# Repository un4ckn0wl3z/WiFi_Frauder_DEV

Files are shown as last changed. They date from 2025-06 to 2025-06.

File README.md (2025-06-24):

# WiFi Frauder 🚨📡

**WiFi Frauder** is an open-source hardware and firmware project designed to broadcast humorous or custom WiFi SSIDs using an ESP32-based custom PCB.

---

## 🟩 PCB Overview

rev3_pcb_assembly
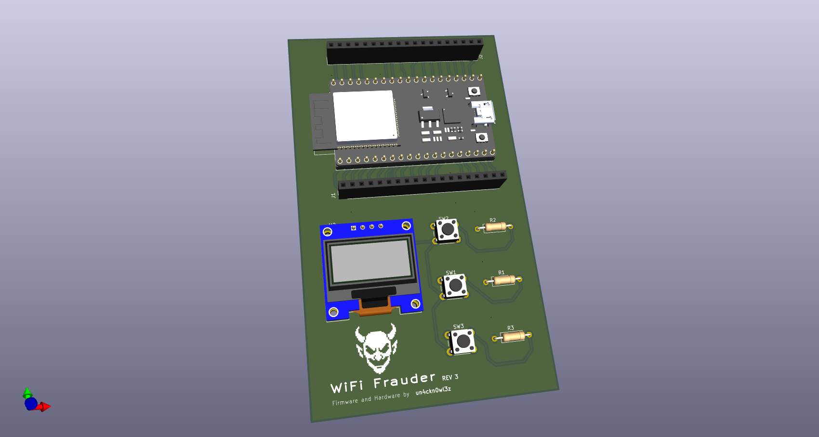
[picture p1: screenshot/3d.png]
3d

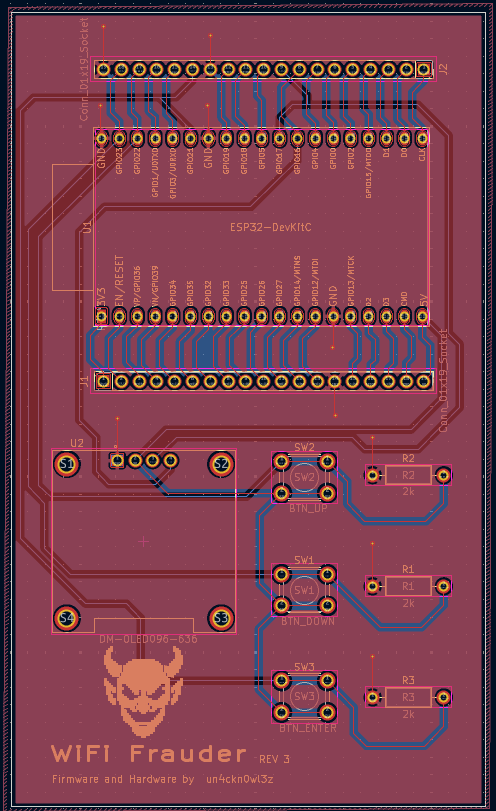
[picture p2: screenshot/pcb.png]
pcb

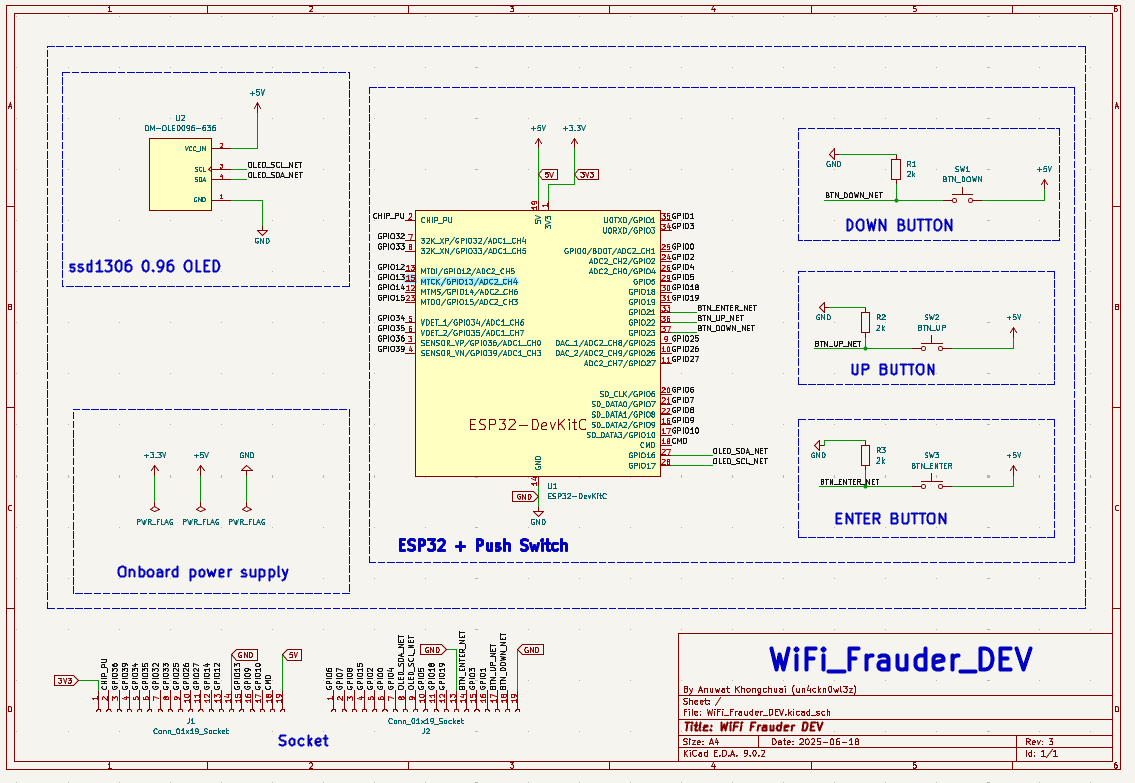
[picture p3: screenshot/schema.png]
schema


---

## 🔧 Features

- Random (Slow) – Randomly spams WiFi SSIDs at a slow rate
- Random (Fast) – Randomly spams WiFi SSIDs at a faster rate
- Custom SSID – Spams WiFi SSIDs based on entries from the SPIFFS config file

---

## To stop spamming
- Press both the UP and DOWN buttons simultaneously to stop spamming.

---

## 🛠️ Hardware

- **Microcontroller**: ESP32 DevKitC 32E (38 pins)
- **Power**: USB or battery-powered
- **Display**: SSD1306 0.96 I2C OLED

PCB design files and schematics are included in the `/pcb` folder.

---

## 📦 Firmware

Written in C++ using the Arduino and FreeRTOS frameworks, built with the PlatformIO toolset.
First, build the SPIFFS file system and edit the SSIDs as you like in the `funny_ssid_list.txt` file located in the `/data` folder.
Then, build the main firmware and upload it to the `WiFi Frauder` device.

---
## Disclaimer

⚠️ Intended for educational and ethical hacking use only. Use responsibly and **never** violate local laws or network policies.

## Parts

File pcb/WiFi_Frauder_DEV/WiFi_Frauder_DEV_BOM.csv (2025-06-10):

Id | Designator | Footprint | Quantity | Designation | Supplier and ref
1 | R2,R1,R3 | C_0805_2012Metric | 3 | 2k
2 | U2 | MODULE_DM-OLED096-636 | 1 | DM-OLED096-636
3 | SW2 | SW_PUSH_6mm | 1 | BTN_UP
4 | SW3 | SW_PUSH_6mm | 1 | BTN_ENTER
5 | U1 | ESP32-DevKitC | 1 | ESP32-DevKitC
6 | SW1 | SW_PUSH_6mm | 1 | BTN_DOWN

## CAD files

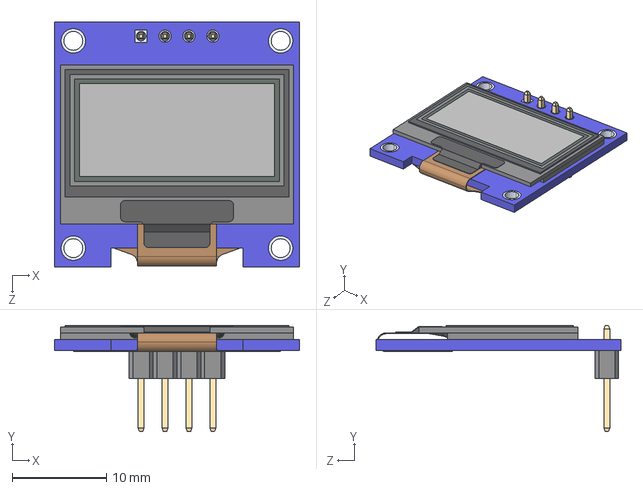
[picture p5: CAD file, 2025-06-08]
pcb/WiFi_Frauder_DEV/DM-OLED096-636/DM-OLED096-636.step
26.0 x 11.3 x 26.0 mm
DM-OLED096-636_Module
DM-OLED096-636_Panel

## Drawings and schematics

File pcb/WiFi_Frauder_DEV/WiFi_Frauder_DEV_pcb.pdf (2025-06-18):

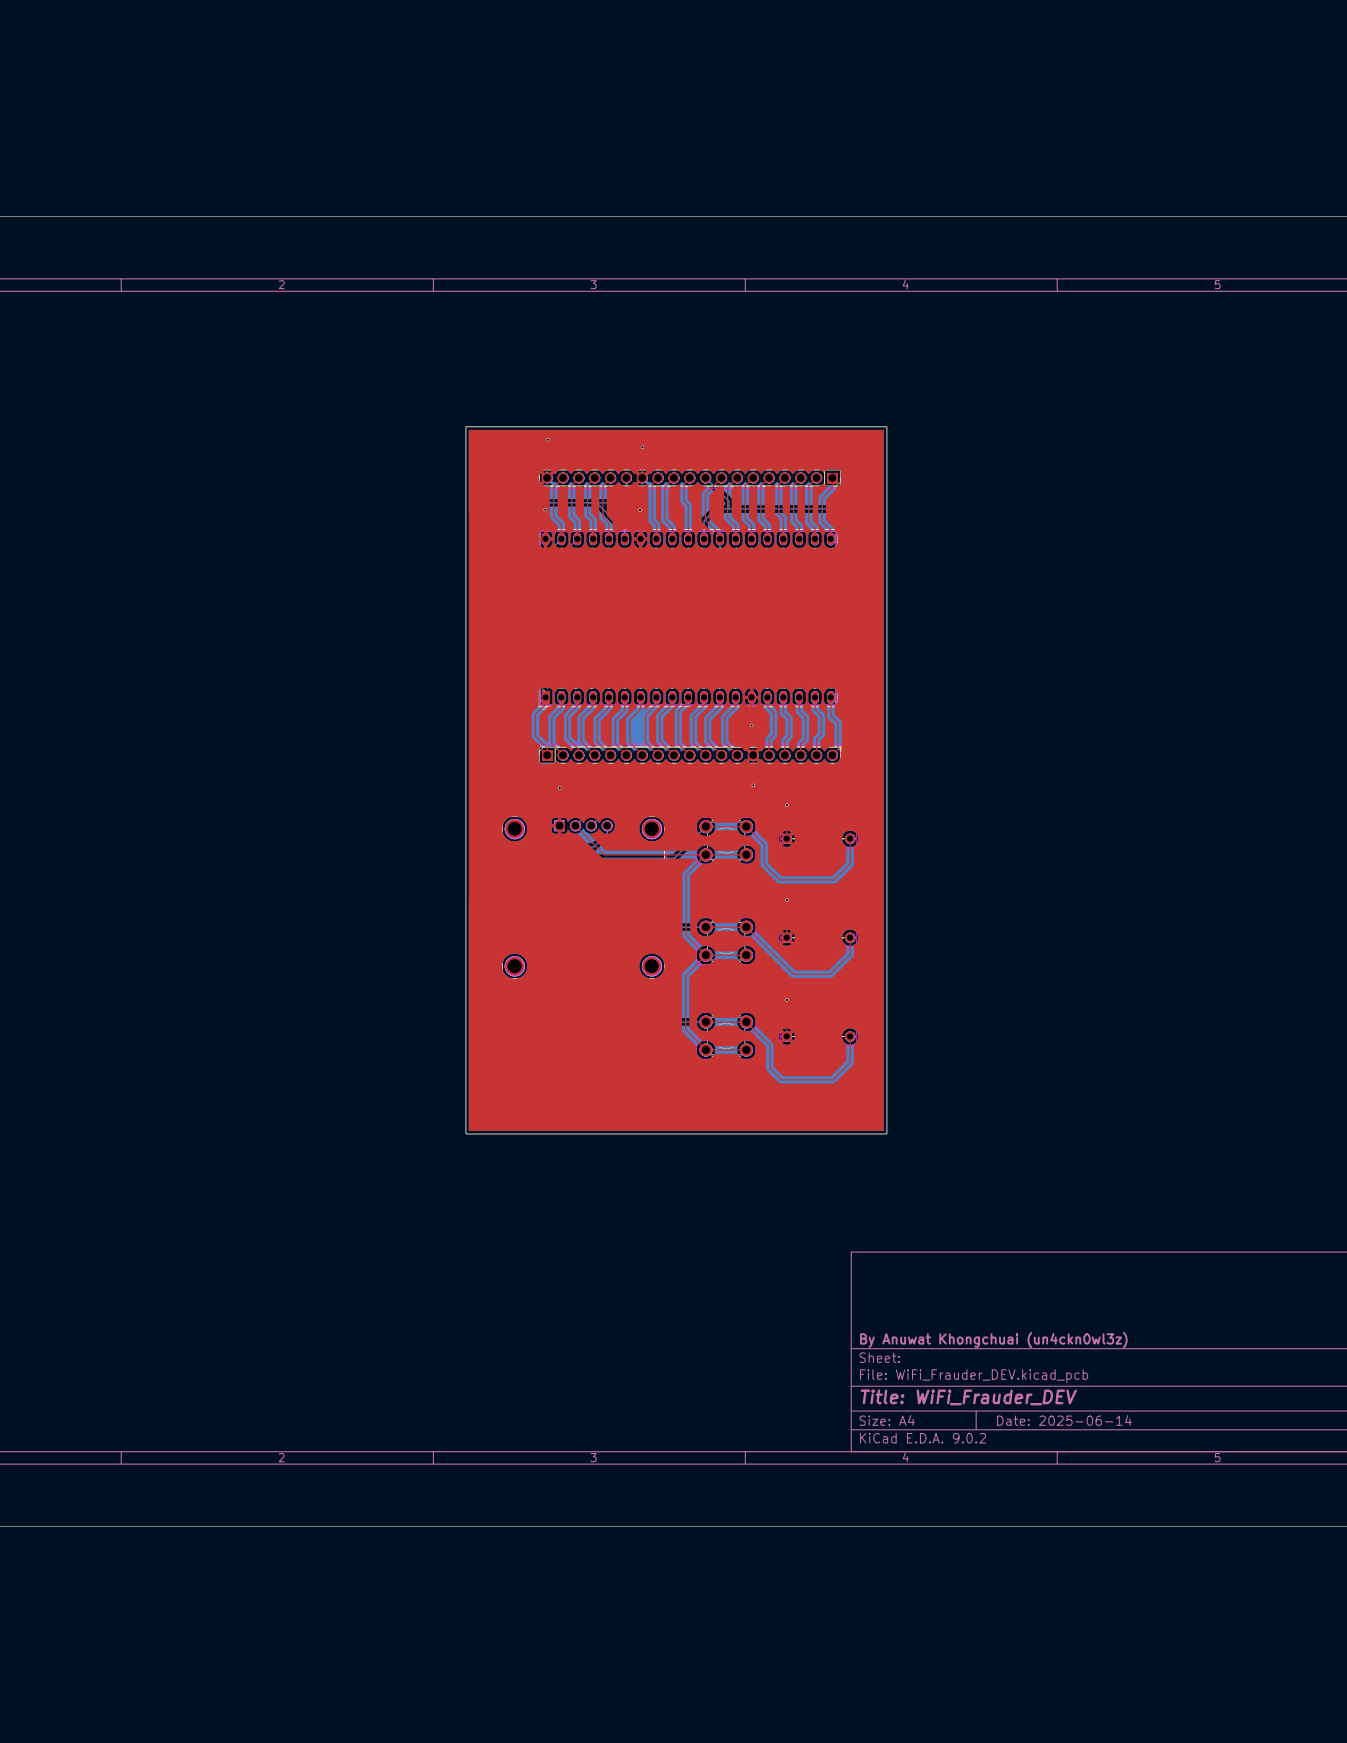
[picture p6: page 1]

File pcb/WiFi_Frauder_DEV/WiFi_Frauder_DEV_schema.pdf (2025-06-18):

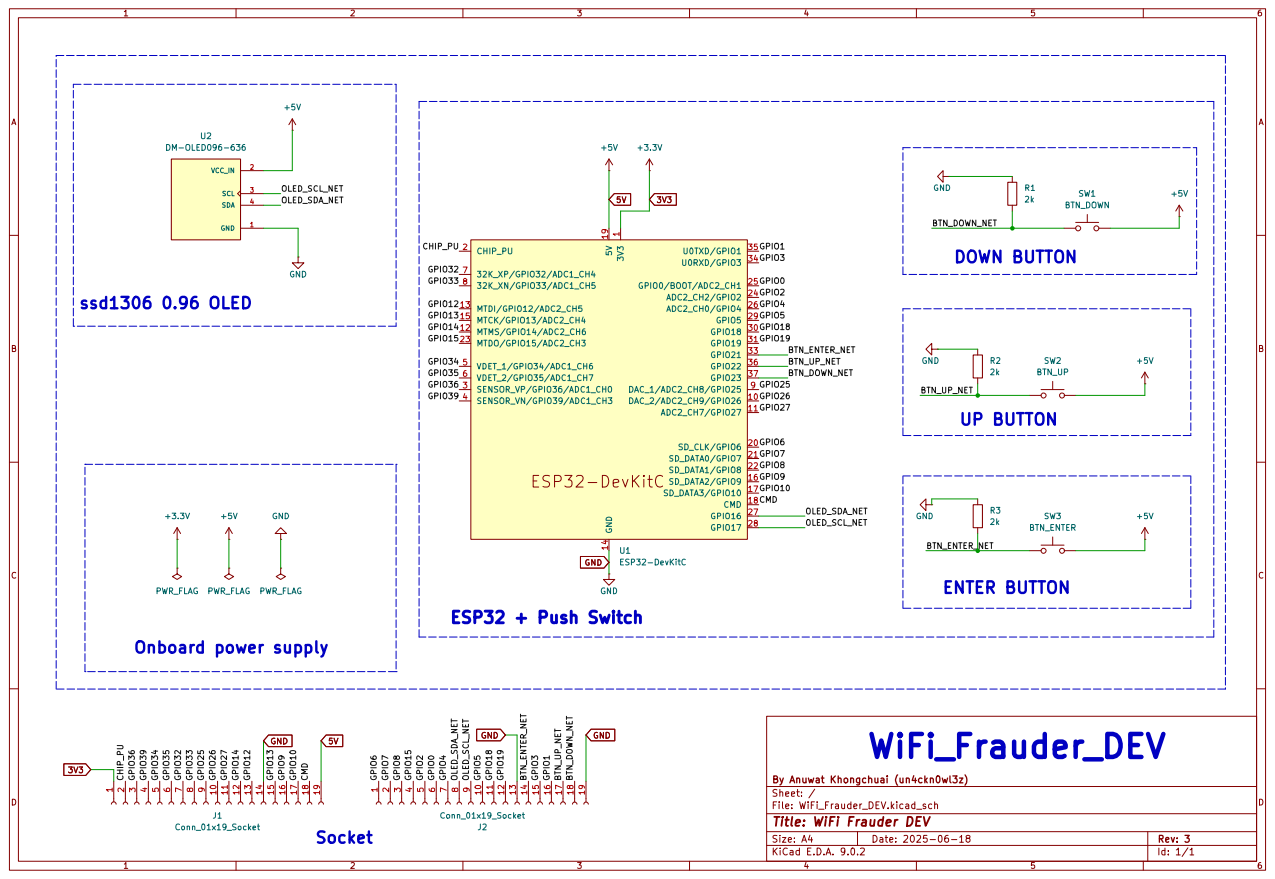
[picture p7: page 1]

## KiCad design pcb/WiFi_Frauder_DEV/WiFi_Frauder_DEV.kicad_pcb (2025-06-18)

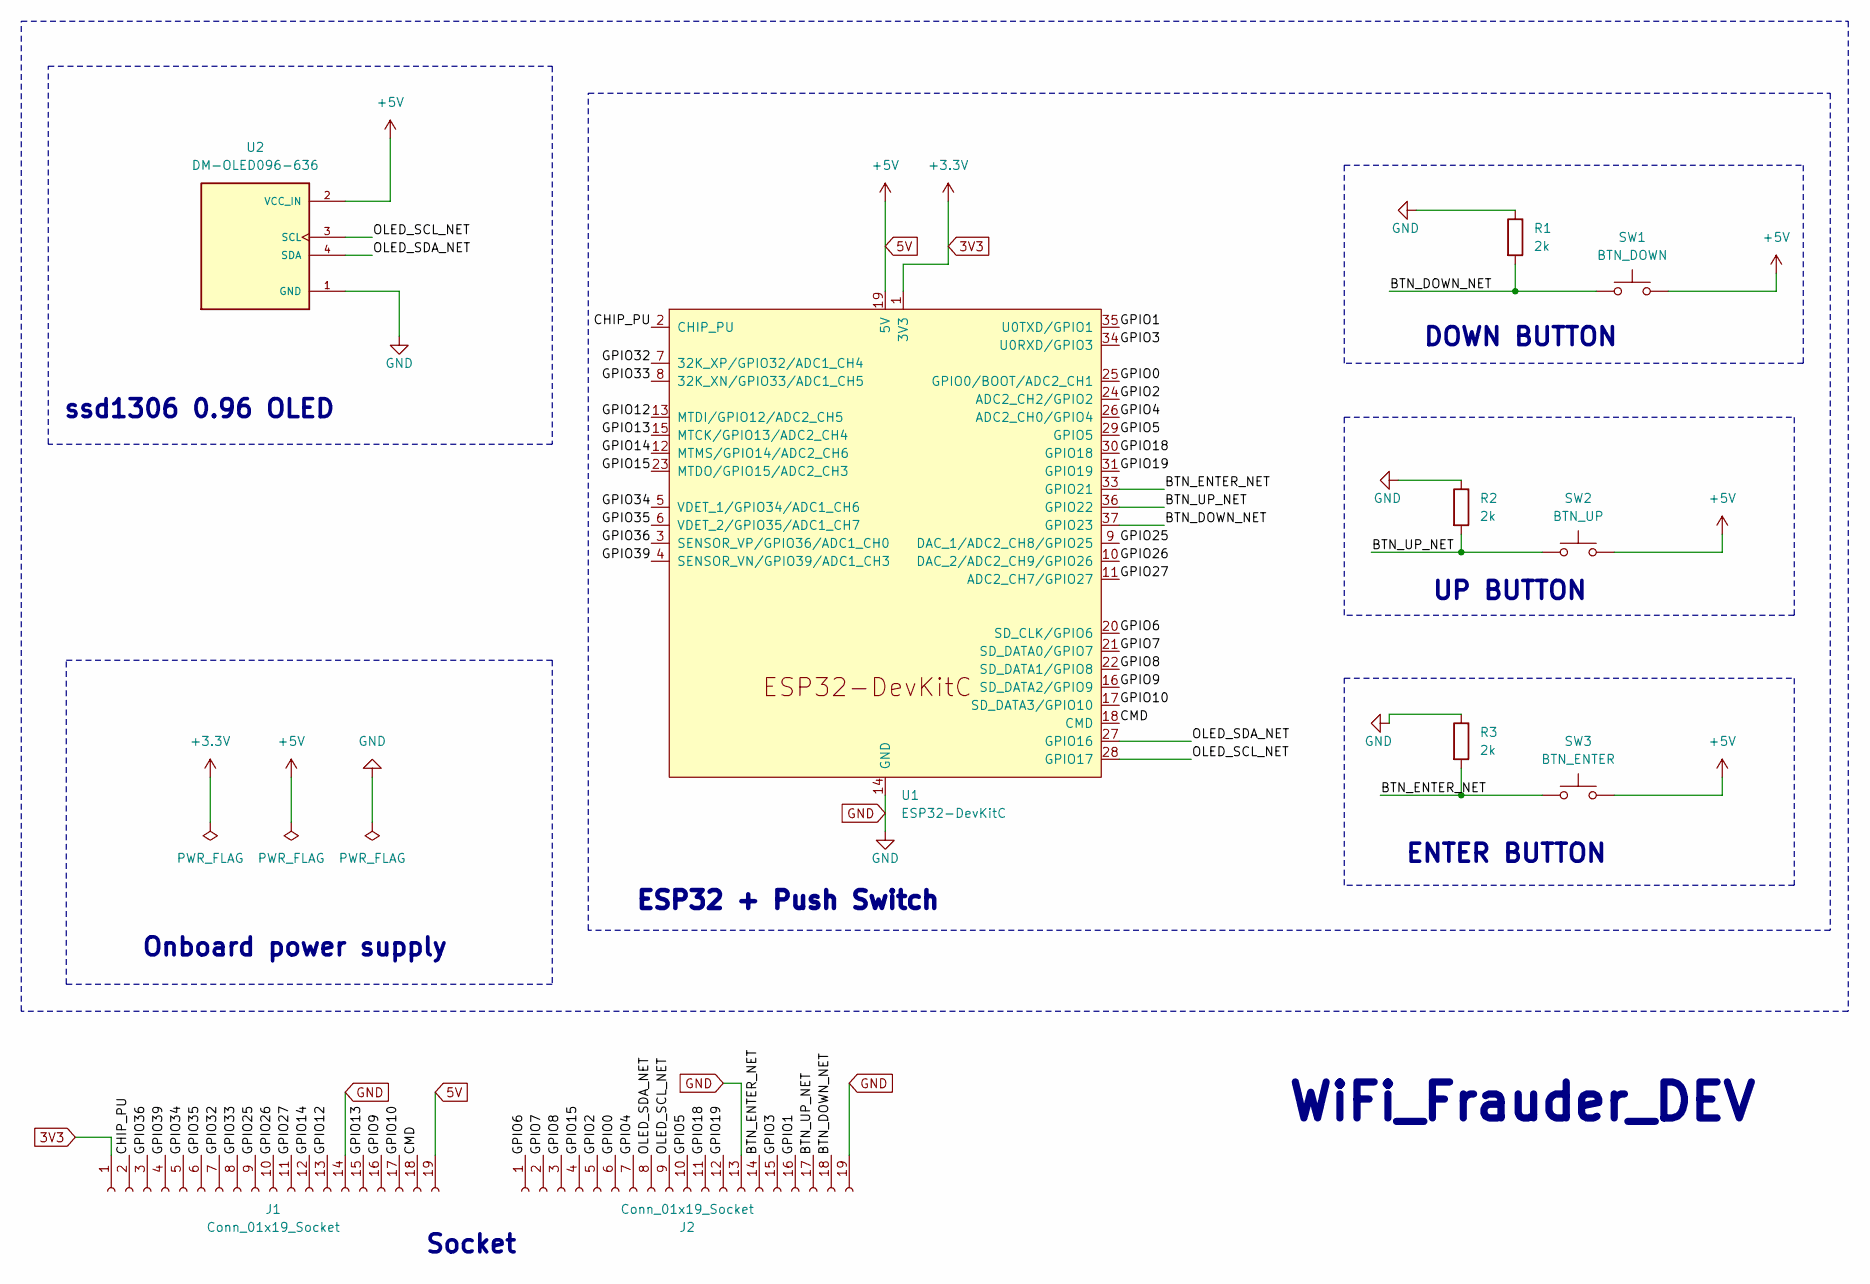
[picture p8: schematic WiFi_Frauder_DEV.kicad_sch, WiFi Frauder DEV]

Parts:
J1, J2: Conn_01x19_Socket; PinSocket_1x19_P2.54mm_Vertical
R1, R2, R3: 2k; R_Axial_DIN0207_L6.3mm_D2.5mm_P10.16mm_Horizontal
SW1: BTN_DOWN; SW_PUSH_6mm
SW2: BTN_UP; SW_PUSH_6mm
SW3: BTN_ENTER; SW_PUSH_6mm
U1: ESP32-DevKitC
U2: DM-OLED096-636; MODULE_DM-OLED096-636; PARTREV 2018-09-10

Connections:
3V3: J1.1, U1.1 (3V3)
5V: J1.19, SW1.2, SW2.2, SW3.2, U1.19 (5V), U2.2 (VCC_IN)
/BTN_DOWN_NET: J2.18, R1.2, SW1.1, U1.37 (GPIO23)
/BTN_ENTER_NET: J2.14, R3.2, SW3.1, U1.33 (GPIO21)
/BTN_UP_NET: J2.17, R2.2, SW2.1, U1.36 (GPIO22)
/CHIP_PU: J1.2, U1.2 (CHIP_PU)
/CMD: J1.18, U1.18 (CMD)
/GPIO0: J2.6, U1.25 (GPIO0/BOOT/ADC2_CH1)
/GPIO1: J2.16, U1.35 (U0TXD/GPIO1)
/GPIO2: J2.5, U1.24 (ADC2_CH2/GPIO2)
/GPIO3: J2.15, U1.34 (U0RXD/GPIO3)
/GPIO4: J2.7, U1.26 (ADC2_CH0/GPIO4)
/GPIO5: J2.10, U1.29 (GPIO5)
/GPIO6: J2.1, U1.20 (SD_CLK/GPIO6)
/GPIO7: J2.2, U1.21 (SD_DATA0/GPIO7)
/GPIO8: J2.3, U1.22 (SD_DATA1/GPIO8)
/GPIO9: J1.16, U1.16 (SD_DATA2/GPIO9)
/GPIO10: J1.17, U1.17 (SD_DATA3/GPIO10)
/GPIO12: J1.13, U1.13 (MTDI/GPIO12/ADC2_CH5)
/GPIO13: J1.15, U1.15 (MTCK/GPIO13/ADC2_CH4)
/GPIO14: J1.12, U1.12 (MTMS/GPIO14/ADC2_CH6)
/GPIO15: J2.4, U1.23 (MTDO/GPIO15/ADC2_CH3)
/GPIO18: J2.11, U1.30 (GPIO18)
/GPIO19: J2.12, U1.31 (GPIO19)
/GPIO25: J1.9, U1.9 (DAC_1/ADC2_CH8/GPIO25)
/GPIO26: J1.10, U1.10 (DAC_2/ADC2_CH9/GPIO26)
/GPIO27: J1.11, U1.11 (ADC2_CH7/GPIO27)
/GPIO32: J1.7, U1.7 (32K_XP/GPIO32/ADC1_CH4)
/GPIO33: J1.8, U1.8 (32K_XN/GPIO33/ADC1_CH5)
/GPIO34: J1.5, U1.5 (VDET_1/GPIO34/ADC1_CH6)
/GPIO35: J1.6, U1.6 (VDET_2/GPIO35/ADC1_CH7)
/GPIO36: J1.3, U1.3 (SENSOR_VP/GPIO36/ADC1_CH0)
/GPIO39: J1.4, U1.4 (SENSOR_VN/GPIO39/ADC1_CH3)
/OLED_SCL_NET: J2.9, U1.28 (GPIO17), U2.3 (SCL)
/OLED_SDA_NET: J2.8, U1.27 (GPIO16), U2.4 (SDA)
GND: J1.14, J2.13, J2.19, R1.1, R2.1, R3.1, U1.14 (GND), U1.32 (GND), U1.38 (GND), U2.1 (GND)

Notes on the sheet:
WiFi_Frauder_DEV
ESP32 + Push Switch
Onboard power supply
DOWN BUTTON
ENTER BUTTON
ssd1306 0.96 OLED
UP BUTTON
Socket

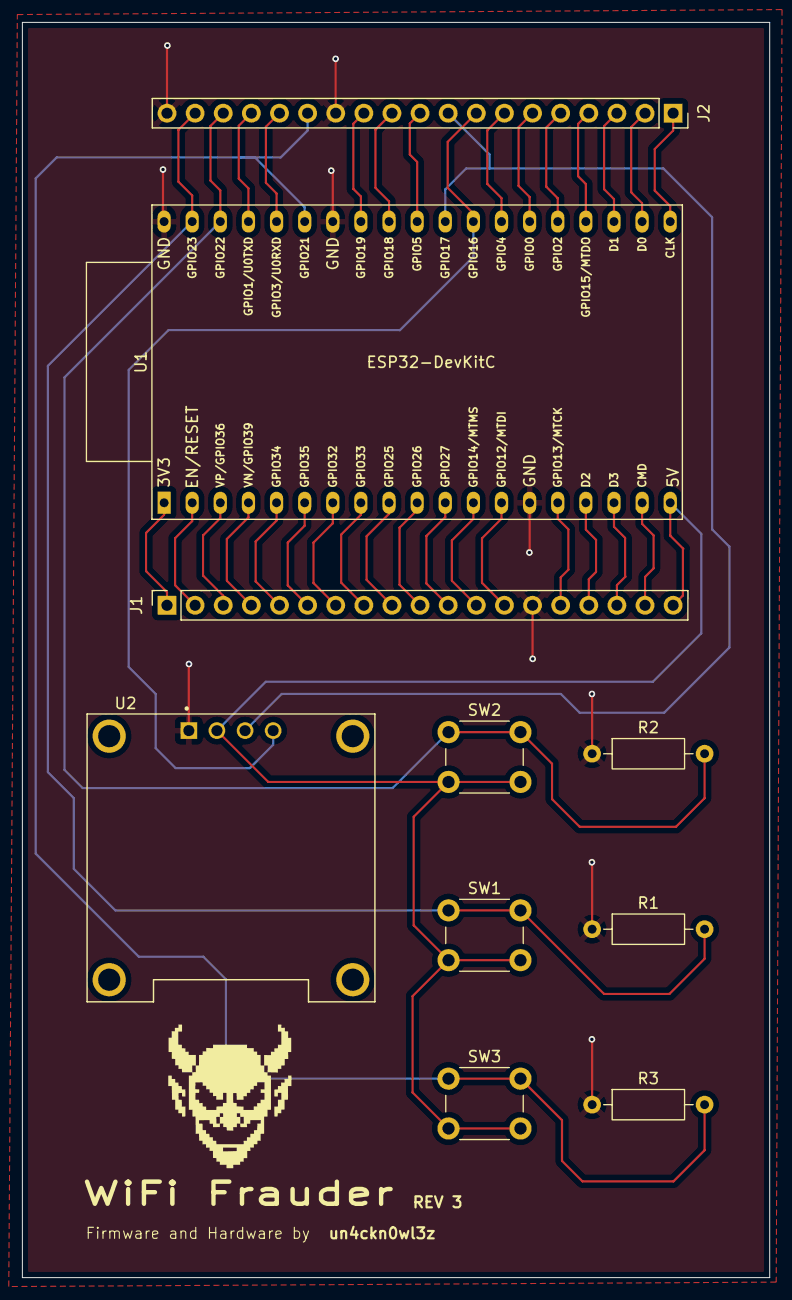
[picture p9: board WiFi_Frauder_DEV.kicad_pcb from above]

Board: 2 copper layers, 67.5 x 113.4 mm, 10 parts (0 on the bottom side), 36 nets.

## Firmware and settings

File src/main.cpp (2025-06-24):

// main.cpp
#include "main.h"

// Initialize display
Adafruit_SSD1306 display(SCREEN_WIDTH, SCREEN_HEIGHT, &Wire, OLED_RESET);

// Devil logo
const uint8_t DEVIL_LOGO[] PROGMEM = {
    0x00,0x00,0x00,0x00,0x00,0x00,0x00,0x00,0x00,0x00,0x00,0x00,0x00,0x00,0x00,0x00,
    0x00,0x00,0x00,0x00,0x00,0x00,0x00,0x00,0x00,0x00,0x00,0x00,0x00,0x00,0x00,0x00,
    0x00,0x00,0x00,0x00,0x00,0x00,0x00,0x00,0x00,0x00,0x00,0x00,0x00,0x00,0x00,0x00,
    0x00,0x00,0x00,0x00,0x00,0x0c,0x00,0x00,0x00,0x00,0x10,0x00,0x00,0x00,0x00,0x00,
    0x00,0x00,0x00,0x00,0x00,0x1c,0x00,0x00,0x00,0x00,0x38,0x00,0x00,0x00,0x00,0x00,
    0x00,0x00,0x00,0x00,0x00,0x38,0x00,0x00,0x00,0x00,0x1c,0x00,0x00,0x00,0x00,0x00,
    0x00,0x00,0x00,0x00,0x00,0x30,0x00,0x00,0x00,0x00,0x0c,0x00,0x00,0x00,0x00,0x00,
    0x00,0x00,0x00,0x00,0x00,0x30,0x00,0x00,0x00,0x00,0x0c,0x00,0x00,0x00,0x00,0x00,
    0x00,0x00,0x00,0x00,0x00,0xf0,0x00,0x00,0x00,0x00,0x0f,0x00,0x00,0x00,0x00,0x00,
    0x00,0x00,0x00,0x00,0x00,0xf0,0x00,0x00,0x00,0x00,0x0f,0x00,0x00,0x00,0x00,0x00,
    0x00,0x00,0x00,0x00,0x00,0xfc,0x00,0x7f,0xfe,0x00,0x1f,0x00,0x00,0x00,0x00,0x00,
    0x00,0x00,0x00,0x00,0x00,0xfe,0x01,0xff,0xff,0x80,0x7f,0x00,0x00,0x00,0x00,0x00,
    0x00,0x00,0x00,0x00,0x00,0x7f,0x03,0xff,0xff,0xc0,0xfe,0x00,0x00,0x00,0x00,0x00,
    0x00,0x00,0x00,0x00,0x00,0x3f,0x07,0xff,0xff,0xe0,0xfc,0x00,0x00,0x00,0x00,0x00,
    0x00,0x00,0x00,0x00,0x00,0x3f,0xef,0xff,0xff,0xf7,0xfc,0x00,0x00,0x00,0x00,0x00,
    0x00,0x00,0x00,0x00,0x00,0x1f,0xef,0x7f,0xff,0xf7,0xf8,0x00,0x00,0x00,0x00,0x00,
    0x00,0x00,0x00,0x00,0x00,0x1f,0xef,0xff,0xff,0xf7,0xf8,0x00,0x00,0x00,0x00,0x00,
    0x00,0x00,0x00,0x00,0x00,0x1f,0xef,0xff,0xff,0xf7,0xf8,0x00,0x00,0x00,0x00,0x00,
    0x00,0x00,0x00,0x00,0x00,0x0f,0x9f,0xff,0xff,0xf9,0xf0,0x00,0x00,0x00,0x00,0x00,
    0x00,0x00,0x00,0x00,0x00,0x07,0x9f,0xff,0xff,0xf9,0xe0,0x00,0x00,0x00,0x00,0x00,
    0x00,0x00,0x00,0x00,0x00,0x00,0x3f,0xff,0xff,0xfc,0x00,0x00,0x00,0x00,0x00,0x00,
    0x00,0x00,0x00,0x00,0x00,0x00,0x7f,0xff,0xff,0xfe,0x00,0x00,0x00,0x00,0x00,0x00,
    0x00,0x00,0x00,0x00,0x00,0xc0,0xff,0xff,0xff,0xff,0x03,0x00,0x00,0x00,0x00,0x00,
    0x00,0x00,0x00,0x00,0x00,0xe0,0xff,0xff,0xff,0xff,0x07,0x00,0x00,0x00,0x00,0x00,
    0x00,0x00,0x00,0x00,0x00,0xf0,0xe7,0xff,0xff,0xe7,0x0f,0x00,0x00,0x00,0x00,0x00,
    0x00,0x00,0x00,0x00,0x00,0x70,0xe3,0xff,0xff,0xc7,0x1e,0x00,0x00,0x00,0x00,0x00,
    0x00,0x00,0x00,0x00,0x00,0x3c,0xe1,0xff,0xff,0x87,0x3c,0x00,0x00,0x00,0x00,0x00,
    0x00,0x00,0x00,0x00,0x00,0x3e,0xf0,0xff,0xff,0x0f,0x7c,0x00,0x00,0x00,0x00,0x00,
    0x00,0x00,0x00,0x00,0x00,0x36,0xe0,0x7d,0xbe,0x07,0x6c,0x00,0x00,0x00,0x00,0x00,
    0x00,0x00,0x00,0x00,0x00,0x32,0xe0,0x39,0x9c,0x07,0x4c,0x00,0x00,0x00,0x00,0x00,
    0x00,0x00,0x00,0x00,0x00,0x30,0xe0,0x19,0x98,0x07,0x0c,0x00,0x00,0x00,0x00,0x00,
    0x00,0x00,0x00,0x00,0x00,0x18,0xf0,0x01,0x80,0x0f,0x18,0x00,0x00,0x00,0x00,0x00,
    0x00,0x00,0x00,0x00,0x00,0x18,0xf8,0x03,0xc0,0x1f,0x18,0x00,0x00,0x00,0x00,0x00,
    0x00,0x00,0x00,0x00,0x00,0x1c,0xfc,0x17,0xe0,0x3f,0x38,0x00,0x00,0x00,0x00,0x00,
    0x00,0x00,0x00,0x00,0x00,0x1e,0xfe,0x1f,0xf8,0x7f,0x78,0x00,0x00,0x00,0x00,0x00,
    0x00,0x00,0x00,0x00,0x00,0x0e,0x3f,0xff,0xff,0xfc,0x70,0x00,0x00,0x00,0x00,0x00,
    0x00,0x00,0x00,0x00,0x00,0x06,0x3f,0xf7,0xef,0xfe,0x60,0x00,0x00,0x00,0x00,0x00,
    0x00,0x00,0x00,0x00,0x00,0x00,0x3f,0xf7,0xe7,0xfc,0x00,0x00,0x00,0x00,0x00,0x00,
    0x00,0x00,0x00,0x00,0x00,0x00,0x1f,0xef,0xf7,0xf8,0x00,0x00,0x00,0x00,0x00,0x00,
    0x00,0x00,0x00,0x00,0x00,0x00,0x10,0xef,0xf7,0x08,0x00,0x00,0x00,0x00,0x00,0x00,
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
};

// Menu and state variables
const char* menu_items[] = {
    "Random WIFI (Slow)", 
    "Random WIFI (Fast)", 
    "Custom WIFI SSID", 
    "About", 
};


volatile bool menu_active = true;
volatile bool spamming = false;
String custom_ssids[64]; // Array for 64 SSIDs from funny_ssid_list.txt
int custom_ssid_count = 0;
const int num_ssids = 64; // Updated to 64 SSIDs for multi-SSID mode
String ssids[64]; // Array for 64 random SSIDs
TaskHandle_t displayTaskHandle = NULL;
TaskHandle_t wifiTaskHandle = NULL;

int current_menu = 0;
int display_start = 0; // Index of first item to display
const int max_display_items = 4; // Number of items to show at once
const int menu_item_count = 4; // Total number of menu items
// Debounce variables
unsigned long lastDebounceTime = 0;
const unsigned long debounceDelay = 300;

void setup() {
    Serial.begin(115200);
    Wire.begin(SDA_PIN, SCL_PIN);
    if (!display.begin(SSD1306_SWITCHCAPVCC, 0x3C)) {
        Serial.println(F("SSD1306 allocation failed"));
        for(;;);
    }
    display.clearDisplay();
    display.display();

    pinMode(BTN_DOWN, INPUT);
    pinMode(BTN_UP, INPUT);
    pinMode(BTN_ENTER, INPUT);

    // Initialize SPIFFS
    if (!SPIFFS.begin(true)) {
        Serial.println(F("SPIFFS Mount Failed"));
        display.clearDisplay();
        display.setTextSize(1);
        display.setTextColor(SSD1306_WHITE);
        display.setCursor(10, 20);
        display.println(F("SPIFFS Mount Failed"));
        display.display();
        for(;;);
    }

    // Read SSID list from file
    if (!readSSIDList()) {
        Serial.println(F("Failed to read funny_ssid_list.txt"));
        display.clearDisplay();
        display.setTextSize(1);
        display.setTextColor(SSD1306_WHITE);
        display.setCursor(10, 20);
        display.println(F("Failed to read funny_ssid_list.txt"));
        display.display();
        vTaskDelay(3000 / portTICK_PERIOD_MS);
    }

    WiFi.mode(WIFI_AP);
    WiFi.softAPdisconnect(true);

    // Generate initial SSIDs for multi-SSID mode
    for (int i = 0; i < num_ssids; i++) {
        ssids[i] = generateRandomSSID();
    }

    // Show logo animation
    displayLogoAnimation();

    // Start display task
    xTaskCreatePinnedToCore(
        displayTask, "DisplayTask", 4096, NULL, 1, &displayTaskHandle, 0);
}

void loop() {
    if (menu_active) {
        if (digitalRead(BTN_DOWN) == HIGH && (millis() - lastDebounceTime) > debounceDelay) {
            current_menu = (current_menu + 1) % menu_item_count; // Updated for new item count
            // Adjust display_start to keep selected item in view
            if (current_menu >= display_start + max_display_items) {
                display_start = current_menu - max_display_items + 1;
            } else if (current_menu < display_start) {
                display_start = current_menu;
            }
            lastDebounceTime = millis();
        }
        if (digitalRead(BTN_UP) == HIGH && (millis() - lastDebounceTime) > debounceDelay) {
            current_menu = (current_menu - 1 + menu_item_count) % menu_item_count; // Updated for new item count
            // Adjust display_start to keep selected item in view
            if (current_menu < display_start) {
                display_start = current_menu;
            } else if (current_menu >= display_start + max_display_items) {
                display_start = current_menu - max_display_items + 1;
            }
            lastDebounceTime = millis();
        }
        if (digitalRead(BTN_ENTER) == HIGH && (millis() - lastDebounceTime) > debounceDelay) {
            menu_active = false;
            // Handle menu selection
            if (menu_items[current_menu] == "Random WIFI (Slow)") {
                xTaskCreatePinnedToCore(spamRandomSSIDSlow, "Random WIFI (Slow) Task", 4096, NULL, 2, &wifiTaskHandle, 1);
            } else if (menu_items[current_menu] == "Random WIFI (Fast)") {
                xTaskCreatePinnedToCore(spamRandomSSIDFast, "Random WIFI (Fast) Task", 4096, NULL, 2, &wifiTaskHandle, 1);
            } else if (menu_items[current_menu] == "Custom WIFI SSID") {
                xTaskCreatePinnedToCore(spamCustomSSID, "Custom WIFI SSID Task", 4096, NULL, 2, &wifiTaskHandle, 1);
            } else if (menu_items[current_menu] == "About") {
                display.clearDisplay();
                display.setTextSize(1);
                display.setTextColor(SSD1306_WHITE);
                display.setCursor(20, 20);
                display.println(F("Developer: UN4"));
                display.setCursor(20, 30);
                display.println(F("HW: ESP32"));
                display.setCursor(20, 40);
                display.println(F("v0.1"));
                display.display();
                vTaskDelay(3000 / portTICK_PERIOD_MS);
                menu_active = true;
            } else {
                display.clearDisplay();
                display.setTextSize(1);
                display.setTextColor(SSD1306_WHITE);
                display.setCursor(20, 20);
                display.println(F("Error:"));
                display.setCursor(20, 30);
                display.println(F("Something wrong"));
                display.setCursor(20, 40);
                display.println(F("!!!!!!!!!!"));
                display.display();
                vTaskDelay(3000 / portTICK_PERIOD_MS);
                menu_active = true;
            }
            lastDebounceTime = millis();
        }
    } else {
        if (digitalRead(BTN_DOWN) == HIGH && digitalRead(BTN_UP) == HIGH && (millis() - lastDebounceTime) > debounceDelay) {
            spamming = false;
            WiFi.softAPdisconnect(true);
            if (wifiTaskHandle != NULL) {
                vTaskDelete(wifiTaskHandle);
                wifiTaskHandle = NULL;
            }
            menu_active = true;
            lastDebounceTime = millis();
        }
    }
}

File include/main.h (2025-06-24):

// main.h
#ifndef MAIN_H
#define MAIN_H

#include <Arduino.h>
#include <Wire.h>
#include <Adafruit_GFX.h>
#include <Adafruit_SSD1306.h>
#include <WiFi.h>
#include <esp_wifi.h>
#include <freertos/FreeRTOS.h>
#include <freertos/task.h>
#include <FS.h>
#include <SPIFFS.h>

// OLED configuration
#define SCREEN_WIDTH 128
#define SCREEN_HEIGHT 64
#define OLED_RESET -1
extern Adafruit_SSD1306 display;

// Pin definitions
#define SDA_PIN 16
#define SCL_PIN 17
#define BTN_DOWN 23
#define BTN_UP 22
#define BTN_ENTER 21

// Devil logo
extern const uint8_t DEVIL_LOGO[];

// Menu and state variables
extern const char* menu_items[];
extern int current_menu;
extern volatile bool menu_active;
extern volatile bool spamming;
extern String custom_ssids[];
extern int custom_ssid_count;
extern const int num_ssids;
extern String ssids[];
extern TaskHandle_t displayTaskHandle;
extern TaskHandle_t wifiTaskHandle;

extern int current_menu;
extern int display_start;
extern const int max_display_items;
extern const int menu_item_count;

// Function declarations
void displayLogoAnimation();
String generateRandomSSID();
void spamRandomSSIDSlow(void *pvParameters);
void spamCustomSSID(void *pvParameters);
void spamRandomSSIDFast(void *pvParameters);
void displayTask(void *pvParameters);
bool readSSIDList();

#endif

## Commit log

2025-06-08 fix: ssid list name
    [main.cpp]
2025-06-08 feat: add pcb
    [DM-OLED096-636.step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]
2025-06-10 feat: revision PCB from 0 to 1
    [WiFi_Frauder_DEV-B_Cu.gbr, WiFi_Frauder_DEV-B_Mask.gbr, WiFi_Frauder_DEV-B_Paste.gbr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]
2025-06-10 fix: schema typo
    [WiFi_Frauder_DEV.kicad_sch]
2025-06-12 feat: revistion pcb to rev2
    [WiFi_Frauder_DEV-B_Cu.gbr, WiFi_Frauder_DEV-B_Mask.gbr, WiFi_Frauder_DEV-B_Paste.gbr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]
2025-06-14 fix: correct schema pinout; remove strapping pin
    [WiFi_Frauder_DEV.kicad_sch]
2025-06-14 feat: re-design pcb
    [WiFi_Frauder_DEV-B_Cu.gbr, WiFi_Frauder_DEV-B_Mask.gbr, WiFi_Frauder_DEV-B_Paste.gbr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]
2025-06-18 feat: re-designed pcb included extended female socket for GPIO
    [WiFi_Frauder_DEV-B_Cu.gbr, WiFi_Frauder_DEV-B_Mask.gbr, WiFi_Frauder_DEV-B_Paste.gbr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]
2025-06-24 feat: add pcb assemble example
2025-06-24 fix: display task bug
    [main.cpp, main.h]
